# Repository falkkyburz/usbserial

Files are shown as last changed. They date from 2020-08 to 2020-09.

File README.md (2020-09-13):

# USB to Serial Converter

This is a USB to serial (UART) converter employing the FTDI FT230XS chip designed in KiCad. I 
included an optional digital isolator for noisy environments or when galvanic 
isolation is required. 

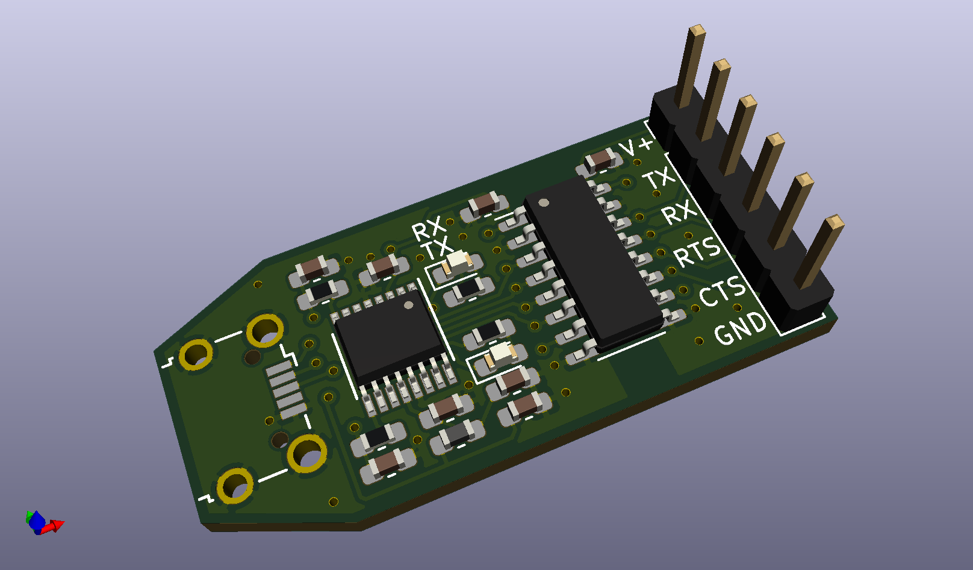
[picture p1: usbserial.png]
usbserial render


## BOM

I also included the interactive html BOM (usbserial.html) 

| References | Value | Footprint | Quantity |
|---|---|---|---|
| C1, C2, C7, C8 | 100n | 0603 | 4 |
| C4, C5 | 47p | 0603 | 2 |
| C3 | 10n | 0603 | 1 |
| C6 | 4.7u | 0603 | 1 |
| R1, R2 | 270R | 0603 | 2 |
| R3, R4 | 27R | 0603 | 2 |
| D1, D2 | green | 0603 | 2 |
| U1 | Si8642BB-B-IS1 | SOIC-16 | 1 |
| U2 | FT230XS | SSOP-16 | 1 |
| FB1 | MI0603J601R-10 | 0603 | 1 |
| JP1 - JP6 | Jumper (if U1 not placed) | 1206 | 6 |
| J1 | Header 4pin, 2.54mm | - | 1 |
| J2 | USB-Micro WE 629105150521 | - | 1 |

## Datasheets

* [Si8642BB-B-IS1](https://www.silabs.com/documents/public/data-sheets/si864x-datasheet.pdf)
* [FT230XS](https://www.ftdichip.com/Support/Documents/DataSheets/ICs/DS_FT230X.pdf)
* [MI0603J601R-10](https://www.laird.com/sites/default/files/2019-04/MI0603J601R-10_0.pdf)
* [WE 629105150521](https://www.we-online.com/catalog/en/COM_MICRO_SMT_TYPE_B_HORIZONTAL_HIGH_CURRENT/)

## Prototype

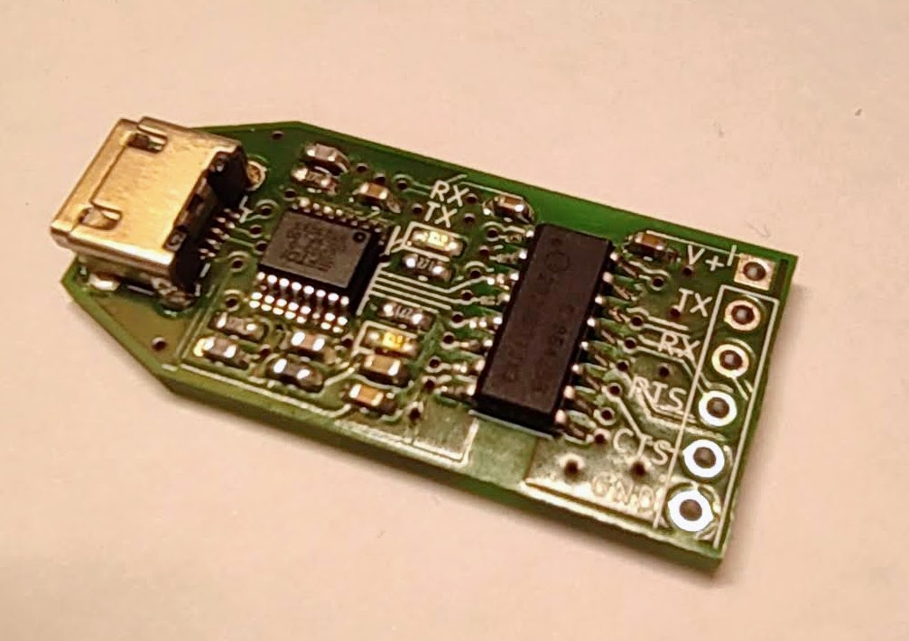
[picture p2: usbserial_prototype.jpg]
usbserial prototype


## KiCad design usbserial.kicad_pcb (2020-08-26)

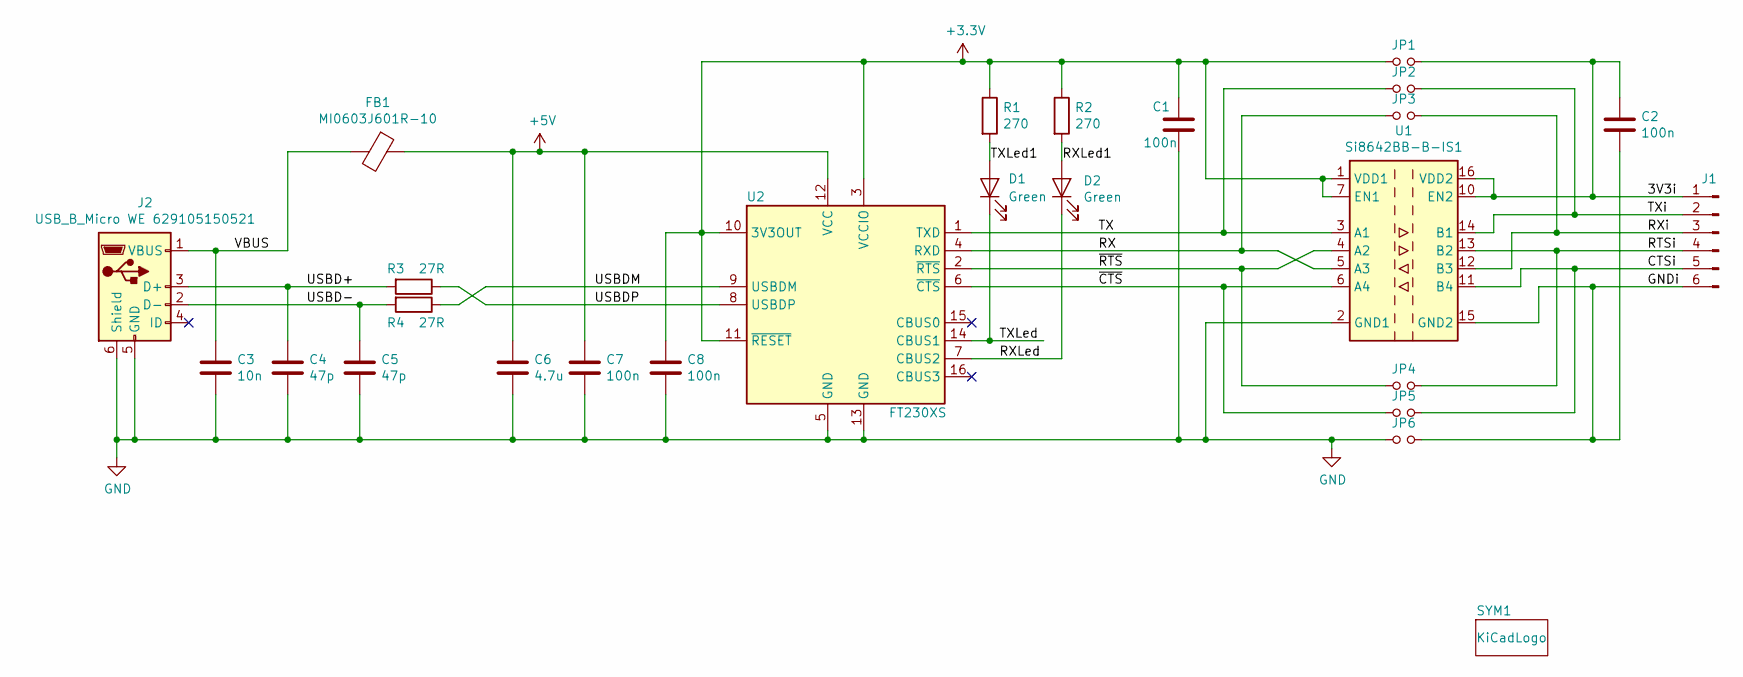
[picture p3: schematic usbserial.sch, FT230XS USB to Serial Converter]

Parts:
C1, C2, C7, C8: 100n; C_0603_1608Metric_Pad1.05x0.95mm_HandSolder
C3: 10n; C_0603_1608Metric_Pad1.05x0.95mm_HandSolder
C4, C5: 47p; C_0603_1608Metric_Pad1.05x0.95mm_HandSolder
C6: 4.7u; C_0603_1608Metric_Pad1.05x0.95mm_HandSolder
D1, D2: Green; LED_0603_1608Metric_Pad1.05x0.95mm_HandSolder
FB1: MI0603J601R-10; L_0603_1608Metric_Pad1.05x0.95mm_HandSolder
J1: Conn_01x06_Male; PinHeader_1x06_P2.54mm_Vertical
J2: USB_B_Micro WE 629105150521; USB_Micro-B_Wuerth_629105150521_CircularHoles
JP1, JP2, JP3, JP4, JP5, JP6: Jumper_NO_Small; R_1206_3216Metric_Pad1.42x1.75mm_HandSolder
R1, R2: 270; R_0603_1608Metric_Pad1.05x0.95mm_HandSolder
R3, R4: 27R; R_0603_1608Metric_Pad1.05x0.95mm_HandSolder
SYM1: KiCadLogo; KiCad-Logo2_5mm_SilkScreen
U1: Si8642BB-B-IS1; SOIC-16_3.9x9.9mm_P1.27mm
U2: FT230XS; SSOP-16_3.9x4.9mm_P0.635mm

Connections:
+3V3: C1.1, C8.1, JP1.1, R1.1, R2.1, U1.1 (VDD1), U1.7 (EN1), U2.3 (VCCIO), U2.10 (3V3OUT), U2.11 (~RESET)
+5V: C6.1, C7.1, FB1.1, U2.12 (VCC)
/3V3i: C2.1, J1.1, JP1.2, U1.10 (EN2), U1.16 (VDD2)
/CTSi: J1.5, JP5.2, U1.11 (B4)
/GNDi: C2.2, J1.6, JP6.2, U1.9 (GND2), U1.15 (GND2)
/RTSi: J1.4, JP4.2, U1.13 (B2)
/RX: JP3.1, U1.5 (A3), U2.4 (RXD)
/RXLed: D2.1 (K), U2.7 (CBUS2)
/RXLed1: D2.2 (A), R2.2
/RXi: J1.3, JP3.2, U1.12 (B3)
/TX: JP2.1, U1.3 (A1), U2.1 (TXD)
/TXLed: D1.1 (K), U2.14 (CBUS1)
/TXLed1: D1.2 (A), R1.2
/TXi: J1.2, JP2.2, U1.14 (B1)
/USBD+: C4.1, J2.3 (D+), R3.2
/USBD-: C5.1, J2.2 (D-), R4.2
/USBDM: R4.1, U2.9 (USBDM)
/USBDP: R3.1, U2.8 (USBDP)
/VBUS: C3.1, FB1.2, J2.1 (VBUS)
/~CTS~: JP5.1, U1.6 (A4), U2.6 (~CTS)
/~RTS~: JP4.1, U1.4 (A2), U2.2 (~RTS)
GND: C1.2, C3.2, C4.2, C5.2, C6.2, C7.2, C8.2, J2.5 (GND), J2.6 (Shield), JP6.1, U1.2 (GND1), U1.8 (GND1), U2.5 (GND), U2.13 (GND)

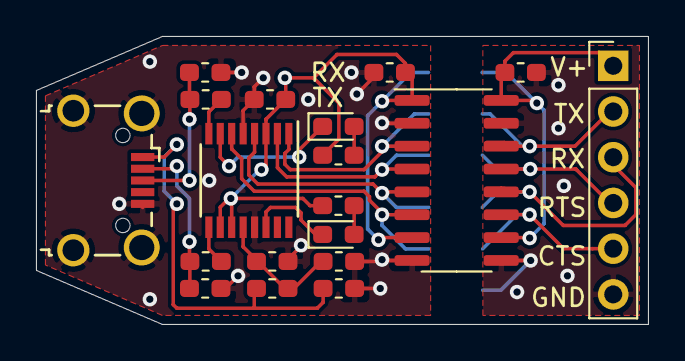
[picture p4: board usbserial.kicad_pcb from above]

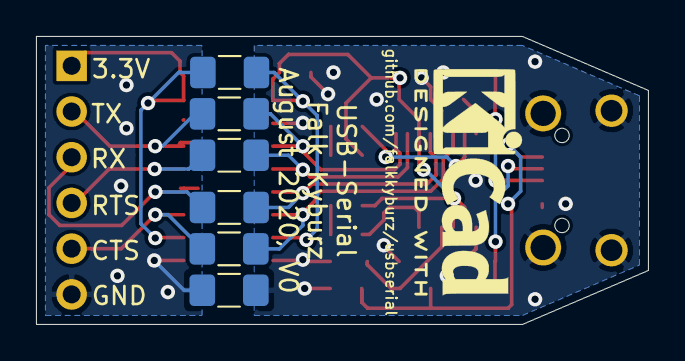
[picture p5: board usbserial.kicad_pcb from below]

Board: 2 copper layers, 34.0 x 16.0 mm, 26 parts (7 on the bottom side), 22 nets.
